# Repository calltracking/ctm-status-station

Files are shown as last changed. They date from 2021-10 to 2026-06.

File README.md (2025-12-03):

# CTM Status Station

Small ESP32 light bar that shows agent call status from CallTrackingMetrics.

## What it does
- Broadcasts its own setup AP on first boot so you can enter Wi‑Fi.
- Lets you link the device to a CTM account via the built-in web UI.
- Listens for ringing/active calls over WebSocket and updates LEDs.

## Hardware
- Tested on TinyPICO / ESP32-S3 dev kits with NeoPixel strip (8 LEDs by default).
- One button: BOOT/RESET. On TinyPICO it hard-resets the board; use the web “Factory Reset” instead.

## Quick start (first-time setup)
1) Power the device. It starts a hotspot:
   - ssid: `ctmlight`
   - pass: `ctmstatus`
2) Connect to the hotspot. A captive portal should pop up; if it doesn’t, open `http://192.168.4.1/` manually.
3) Enter your Wi‑Fi SSID and password. The device reboots and joins your network (LEDs blink green once connected).
4) Find its LAN IP (router/DHCP list or `http://ctmlight.local` if mDNS works) and open `http://<device-ip>/`.
5) Click **Connect Device** to start linking. You’ll get a code and a link to `https://app.calltrackingmetrics.com/accesscode`.
6) Approve the device in CTM. The page polls automatically; once linked the device reboots and starts listening.

## Relinking / factory reset
- From the UI: click **Factory Reset** (on the main page or `/link_setup`) to clear Wi‑Fi and CTM link, then the device reboots back to the `ctmlight` AP.
- If you’re still linked and you reopen `/link`, it will tell you the device is already linked and offer **Unlink Device**.

## Build & flash
Prereqs: PlatformIO (`pio`), Python, USB cable.

Common targets (default `make` builds/uploads TinyPICO):
```
make                         # TinyPICO: build, upload, then serial monitor
pio run -e tinypico          # build only TinyPICO
pio run -e s3wroom_1         # build only ESP32-S3 devkit
make wroom_s3                # ESP32-S3: build + upload
pio device monitor -b 115200 # serial monitor (921600 for s3wroom_1)
make clean                   # cleanup
```

## Development / tunnels
When `CTM_PRODUCTION` is undefined (staging/tunnel), provide hosts and client id:
```
CTM_SOC_HOST=<ngrok>.ngrok.io \
CTM_API_HOST=<ngrok>.ngrok.io \
CTM_APP_HOST=<ngrok>.ngrok.io \
CTM_CLIENTID=<client_id> \
make tinypico
```
Get a client id from https://app.calltrackingmetrics.com/oauth_apps/.

## Ethernet (experimental)
ESP32 Ethernet needs different PEM handling. Use the helper from OPEnSLab-OSU/SSLClient to generate BearSSL certs:
```
python3 pycert_bearssl.py download app.calltrackingmetrics.com --output include/certs.h
```

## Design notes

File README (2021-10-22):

= CTM Status Station

The goal this project is to make it easy to have light in a room that helps people in the area know when someone is on a phone call.

We'll subscribe to incoming phone calls and active call events and change the light color to make this obvious

= Setup

Before the device is configured it will expose an access point: 
  ssid: ctmlight
  pass: ctmstatus

After connecting navigate browser to

http://192.168.4.1/

From the web interface configure your networks ssid and password

Once the device joins your network it'll blink green

You'll have to find the device now on your network

http://your-device-ip/

From here you can click connect and you'll be taken to a page on https://app.calltrackingmetrics give access to the device and you should 
next be presented with some options to choose a specific team or your whole account.

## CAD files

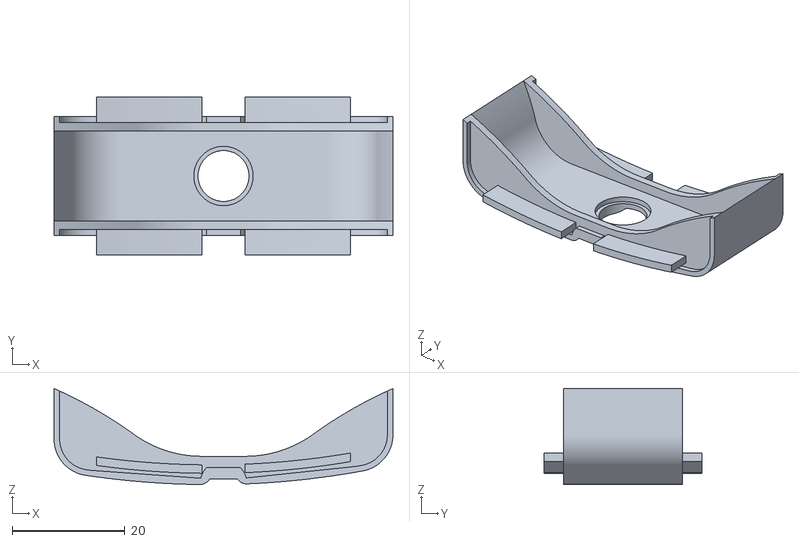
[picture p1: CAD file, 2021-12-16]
case/v2-a.stl
60.0 x 28.0 x 17.0

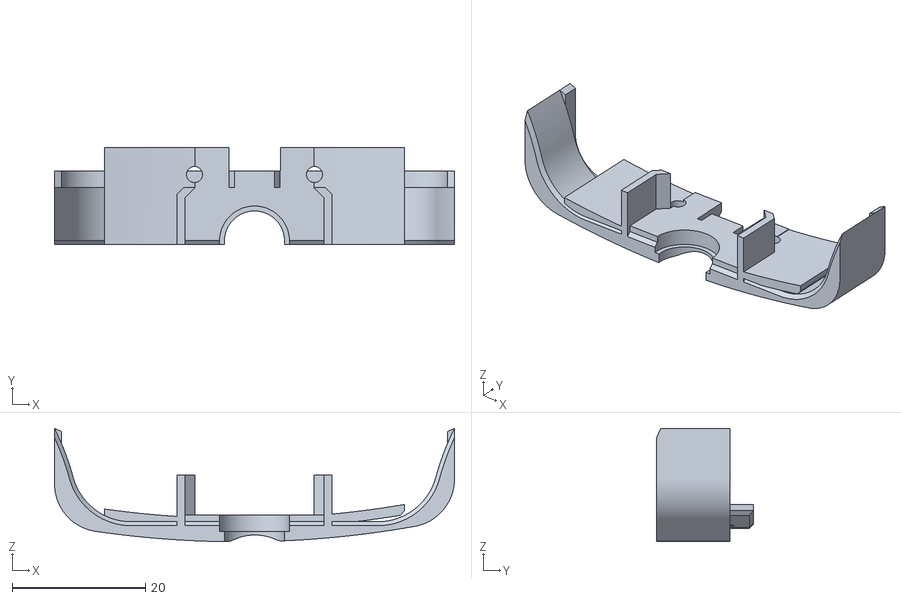
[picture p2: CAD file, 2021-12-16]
case/left.stl
60.0 x 14.5 x 17.0

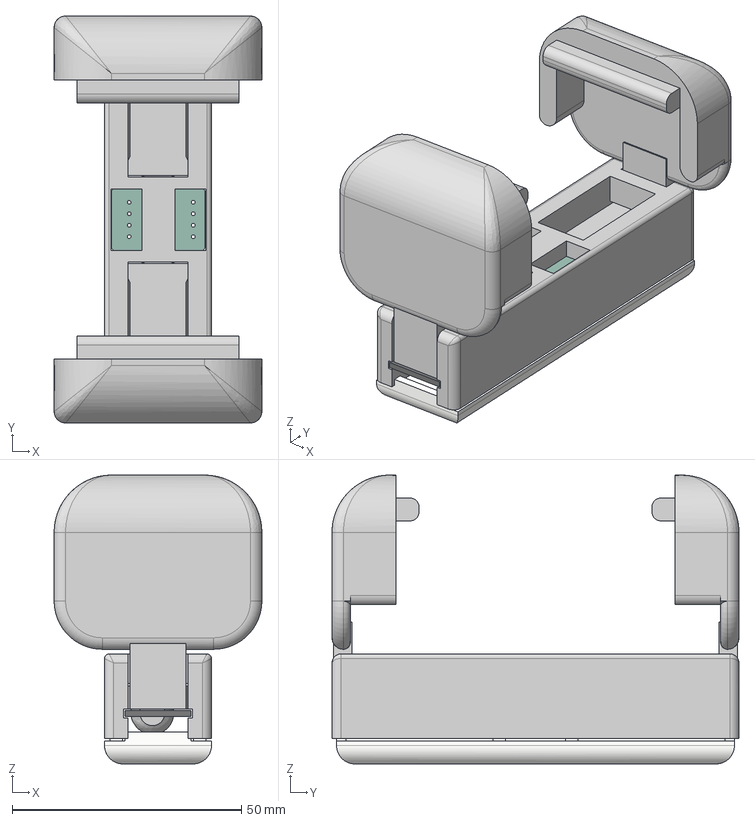
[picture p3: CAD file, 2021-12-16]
case/Case v19.step
45.3 x 88.8 x 63.0 mm

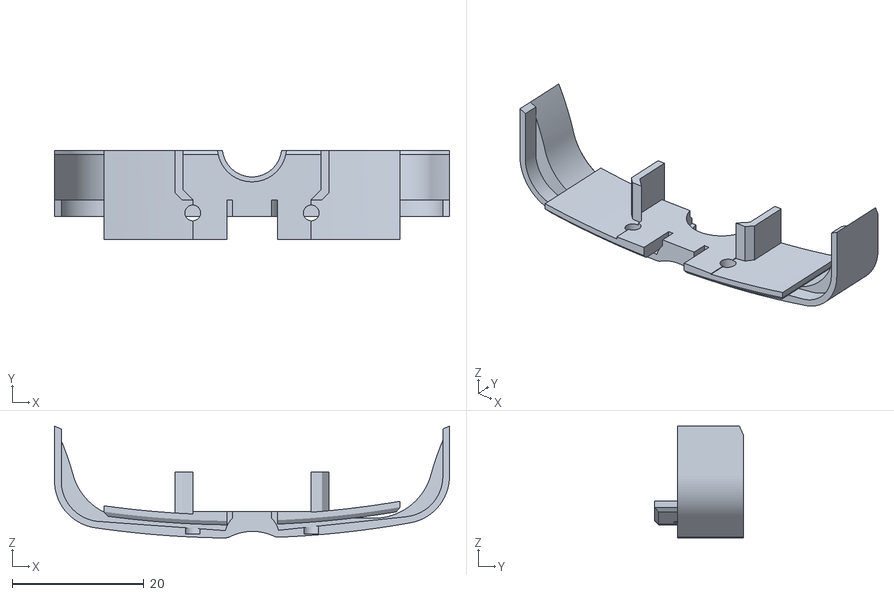
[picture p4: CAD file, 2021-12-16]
case/right.stl
60.0 x 13.5 x 17.0

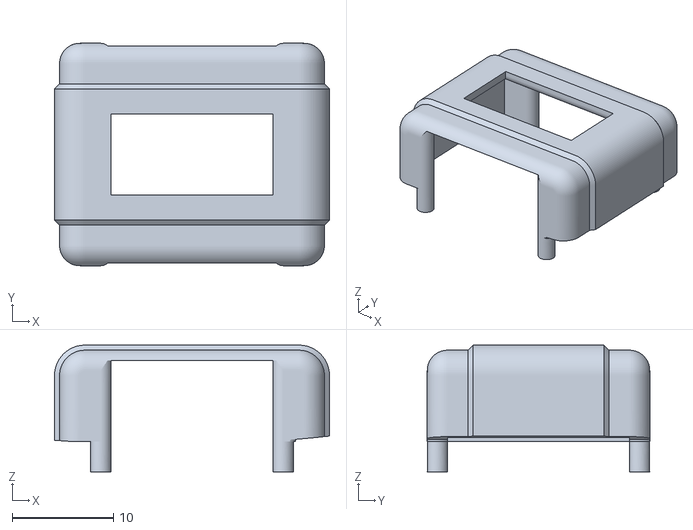
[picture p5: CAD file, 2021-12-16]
case/holder.stl
27.1 x 21.9 x 12.5

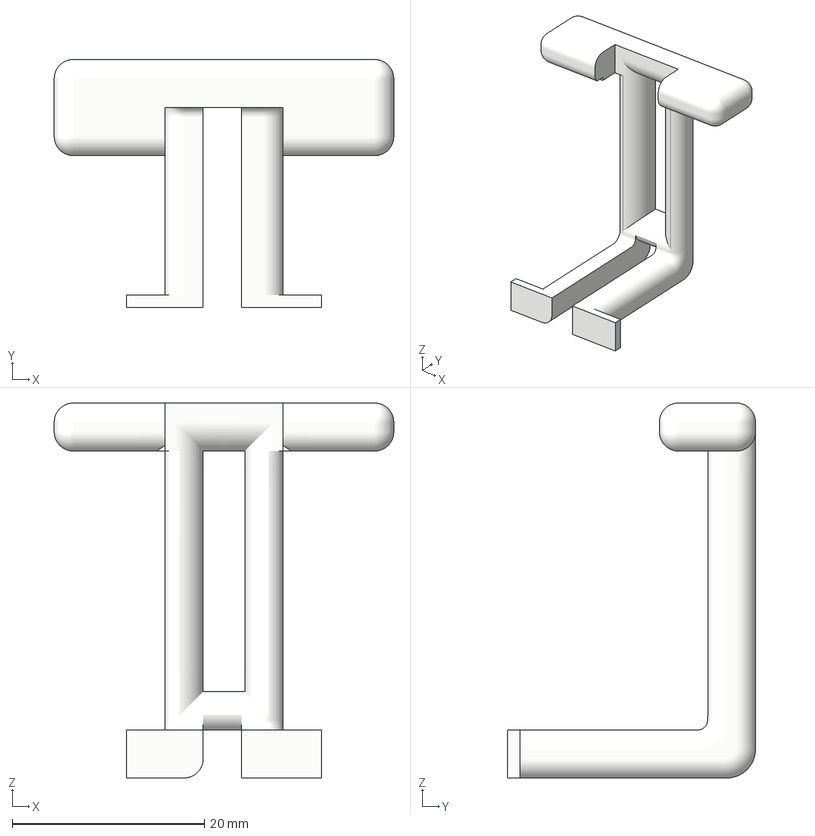
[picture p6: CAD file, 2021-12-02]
case/leg1.3mf
35.3 x 25.8 x 39.0 mm

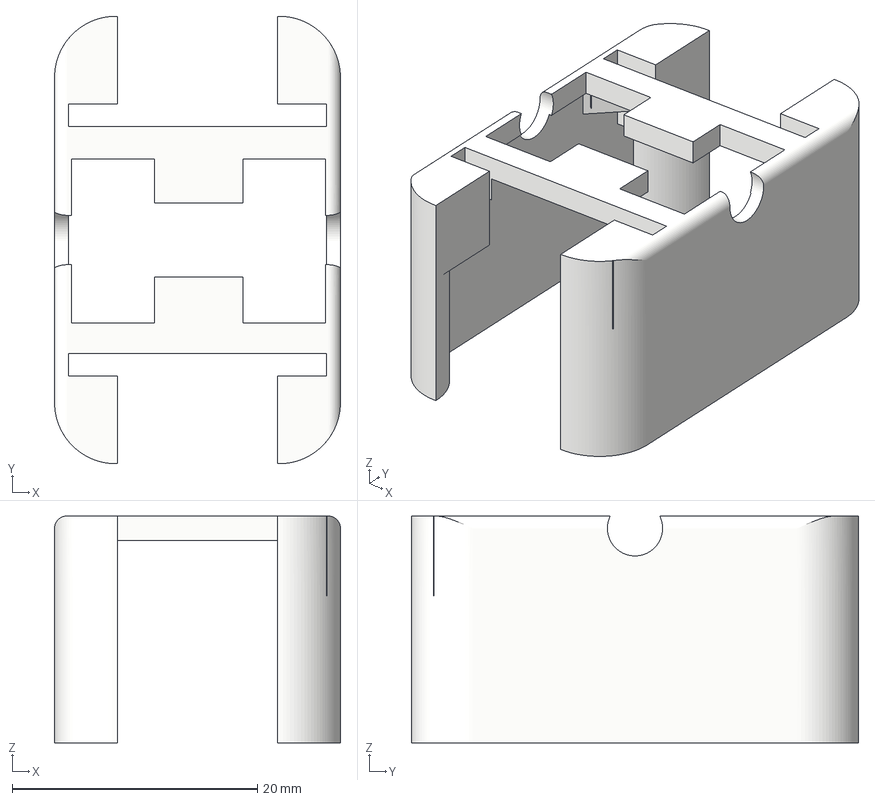
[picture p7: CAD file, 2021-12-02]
case/led-frame.3mf
23.3 x 36.5 x 18.5 mm

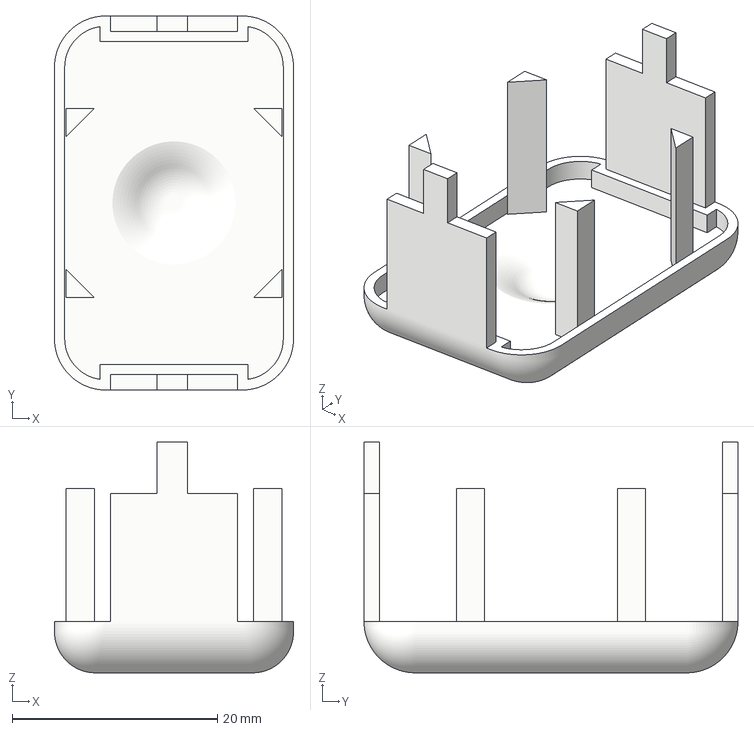
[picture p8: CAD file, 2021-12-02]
case/led-top.3mf
23.3 x 36.5 x 22.5 mm

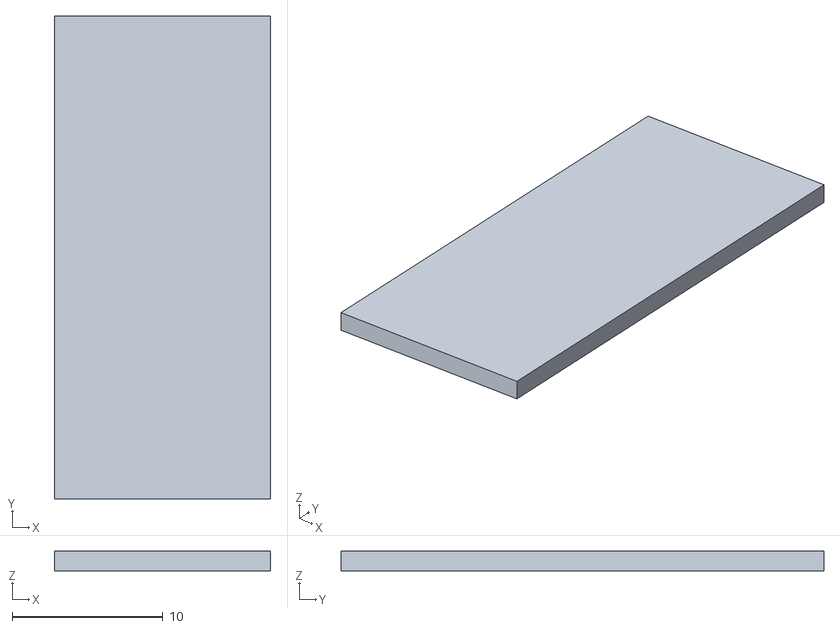
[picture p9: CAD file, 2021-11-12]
case/frame-lock2.stl
14.3 x 32.0 x 1.30

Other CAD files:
case/leg2.3mf
case/frame-lock1.stl
case/led-frame.stl
case/led-top.stl
case/leg1.stl
case/leg2.stl

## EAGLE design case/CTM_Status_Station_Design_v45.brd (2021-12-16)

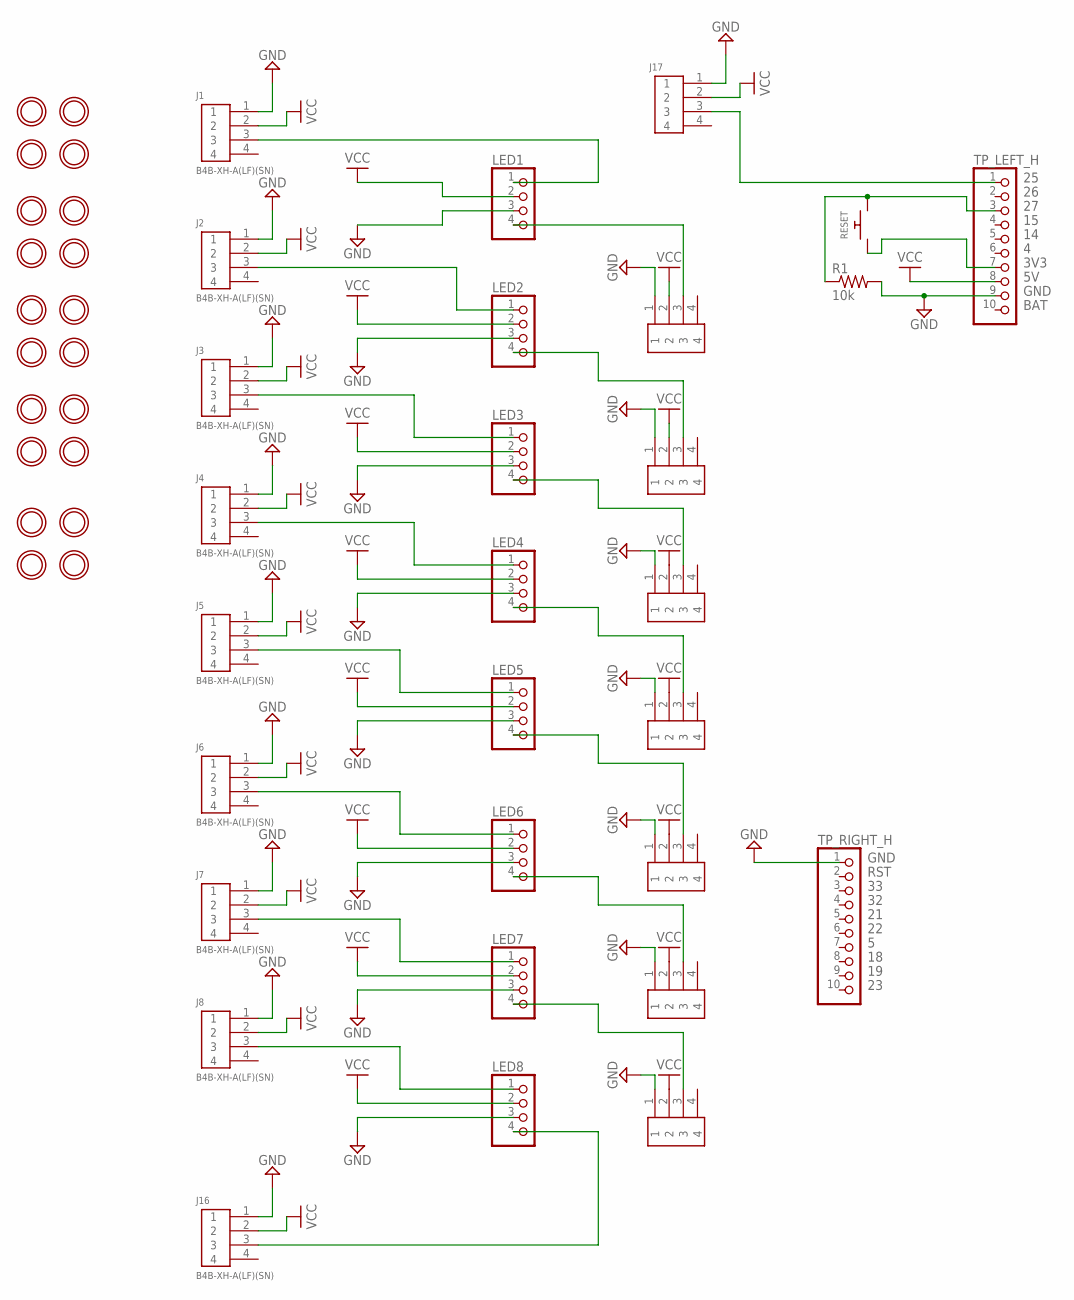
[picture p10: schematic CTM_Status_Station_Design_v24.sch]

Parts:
J1, J2, J3, J4, J5, J6, J7, J8, J9, J10, J11, J12, J13, J14, J15, J16, J17: B4B-XH-A(LF)(SN)
LED1, LED2, LED3, LED4, LED5, LED6, LED7, LED8: PINHD-1X4; 1X04
R1: 10k; 0207/7
RESET: SWITCH_PUSHBUTTONEVQ-PE; TACT_PANA-EVQ
TP_LEFT_H: PINHD-1X10; 1X10
TP_RIGHT_H: PINHD-1X10; 1X10
U$1, U$2, U$3, U$4, U$5, U$6, U$7, U$8, U$9, U$10, U$11, U$12, U$13, U$14, U$15, U$16, U$17, U$18, U$19, U$28: MOUNTINGHOLE2.5; MOUNTINGHOLE_2.5_PLATED

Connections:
3V3: RESET.P$1, TP_LEFT_H.7
DIN1: J1.3, LED1.1
DIN2: J2.3, LED2.1
DIN3: J3.3, LED3.1
DIN4: J4.3, LED4.1
DIN5: J5.3, LED5.1
DIN6: J6.3, LED6.1
DIN7: J7.3, LED7.1
DIN8: J8.3, LED8.1
DOUT: J17.3, TP_LEFT_H.1
DOUT1: J10.3, LED1.4
DOUT2: J9.3, LED2.4
DOUT3: J11.3, LED3.4
DOUT4: J12.3, LED4.4
DOUT5: J13.3, LED5.4
DOUT6: J14.3, LED6.4
DOUT7: J15.3, LED7.4
DOUT8: J16.3, LED8.4
GND: J1.1, J2.1, J3.1, J4.1, J5.1, J6.1, J7.1, J8.1, J9.1, J10.1, J11.1, J12.1, J13.1, J14.1, J15.1, J16.1, J17.1, LED1.3, LED2.3, LED3.3, LED4.3, LED5.3, LED6.3, LED7.3, LED8.3, R1.2, TP_LEFT_H.9, TP_RIGHT_H.1
RESET: R1.1, RESET.P$2, TP_LEFT_H.3
VCC: J1.2, J2.2, J3.2, J4.2, J5.2, J6.2, J7.2, J8.2, J9.2, J10.2, J11.2, J12.2, J13.2, J14.2, J15.2, J16.2, J17.2, LED1.2, LED2.2, LED3.2, LED4.2, LED5.2, LED6.2, LED7.2, LED8.2, TP_LEFT_H.8

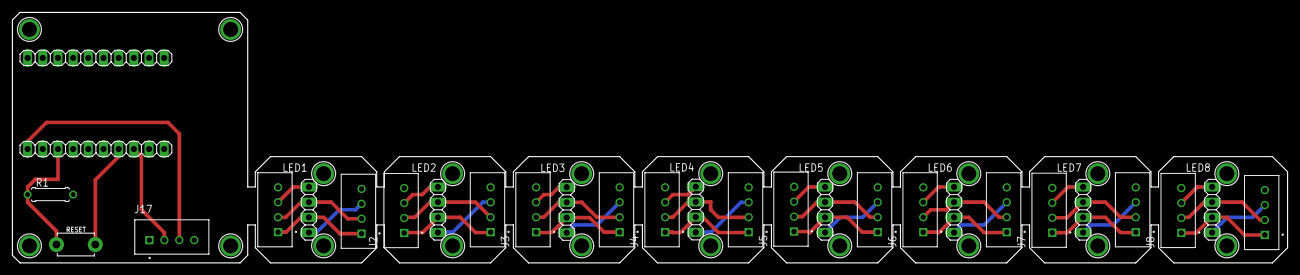
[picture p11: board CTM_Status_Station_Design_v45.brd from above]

Board: 2 copper layers, 213.4 x 41.9 mm, 49 parts (0 on the bottom side), 21 nets.

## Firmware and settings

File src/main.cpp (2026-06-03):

// Copyright (c) 2011-2025 CallTrackingMetrics
// SPDX-License-Identifier: ISC

/**
 * configure and listen for account or team events
 */
#define CTM_PRODUCTION

//#define LIGHT_TEST
#ifndef HAS_DISPLAY
#ifndef WROOM_PINS
#include <TinyPICO.h>
#endif
#endif

#include <SPI.h>
#include <WiFi.h>
#include <WebServer.h>
#include <WiFiClientSecure.h>
#include <HTTPClient.h>
#include <Wire.h>
#include <DNSServer.h>
#include <cstring>
#include <esp_system.h>
#include <esp_timer.h>
#include <ArduinoJson.h> // see: https://arduinojson.org/v6/api/jsonobject/containskey/
#include <ArduinoWebsockets.h>
#include <Adafruit_NeoPixel.h>

#include <WiFiClientSecure.h>

#ifdef HAS_DISPLAY
  #include <Adafruit_GFX.h>
  #include <Adafruit_ThinkInk.h>

  #ifdef ESP32
    #define SRAM_CS     32
    #define EPD_CS      15
    #define EPD_DC      33  
  #endif
#endif

#ifdef __AVR__
 #include <avr/power.h> // Required for 16 MHz Adafruit Trinket
#endif

#include "settings.h"
#include "url_utils.h"
#include "light_logic.h"

#ifdef HAS_DISPLAY

#define EPD_RESET   -1 // can set to -1 and share with microcontroller Reset!
#define EPD_BUSY    -1 // can set to -1 to not use a pin (will wait a fixed delay)

// Uncomment the following line if you are using 2.13" Monochrome EPD with SSD1680
//ThinkInk_213_Mono_BN display(EPD_DC, EPD_RESET, EPD_CS, SRAM_CS, EPD_BUSY);
ThinkInk_213_Mono_B72 display(EPD_DC, EPD_RESET, EPD_CS, SRAM_CS, EPD_BUSY);
//ThinkInk_213_Mono_B73 display(EPD_DC, EPD_RESET, EPD_CS, SRAM_CS, EPD_BUSY);
#define COLOR1 EPD_BLACK
#define COLOR2 EPD_RED

#endif

#ifdef TINYPICO_PINS
#define RESET_BUTTON 0           // TinyPICO BOOT button
#define RESET_BUTTON_ACTIVE LOW  // active-low (pulled up)
#else
#define RESET_BUTTON 27
#define RESET_BUTTON_ACTIVE HIGH
#endif
#define STATUS_LIGHT_OUT 25
#define DO_EXPAND(VAL)  VAL ## 1
#define EXPAND(VAL)     DO_EXPAND(VAL)

#ifdef CTM_PRODUCTION
#if !defined(APP_HOST) || (EXPAND(APP_HOST) == 1)
#undef APP_HOST
#define APP_HOST "app.calltrackingmetrics.com"
#endif
#if !defined(API_HOST) || (EXPAND(API_HOST) == 1)
#undef API_HOST
#define API_HOST "api.calltrackingmetrics.com"
#endif
#if !defined(SOC_HOST) || (EXPAND(SOC_HOST) == 1)
#undef SOC_HOST
#define SOC_HOST "app.calltrackingmetrics.com"
#endif
#if !defined(CLIENTID) || (EXPAND(CLIENTID) == 1)
#undef CLIENTID
#define CLIENTID "udaRmKY2W_85tFPM6f92R9aG8i-VwPjfQT1Q8RI8qIg"
#endif

// amazon root ca for api.calltrackingmetrics.com secure connections
const char *root_ca="-----BEGIN CERTIFICATE-----\n"
"MIIDQTCCAimgAwIBAgITBmyfz5m/jAo54vB4ikPmljZbyjANBgkqhkiG9w0BAQsF\n"
"ADA5MQswCQYDVQQGEwJVUzEPMA0GA1UEChMGQW1hem9uMRkwFwYDVQQDExBBbWF6\n"
"b24gUm9vdCBDQSAxMB4XDTE1MDUyNjAwMDAwMFoXDTM4MDExNzAwMDAwMFowOTEL\n"
"MAkGA1UEBhMCVVMxDzANBgNVBAoTBkFtYXpvbjEZMBcGA1UEAxMQQW1hem9uIFJv\n"
"b3QgQ0EgMTCCASIwDQYJKoZIhvcNAQEBBQADggEPADCCAQoCggEBALJ4gHHKeNXj\n"
"ca9HgFB0fW7Y14h29Jlo91ghYPl0hAEvrAIthtOgQ3pOsqTQNroBvo3bSMgHFzZM\n"
"9O6II8c+6zf1tRn4SWiw3te5djgdYZ6k/oI2peVKVuRF4fn9tBb6dNqcmzU5L/qw\n"
"IFAGbHrQgLKm+a/sRxmPUDgH3KKHOVj4utWp+UhnMJbulHheb4mjUcAwhmahRWa6\n"
"VOujw5H5SNz/0egwLX0tdHA114gk957EWW67c4cX8jJGKLhD+rcdqsq08p8kDi1L\n"
"93FcXmn/6pUCyziKrlA4b9v7LWIbxcceVOF34GfID5yHI9Y/QCB/IIDEgEw+OyQm\n"
"jgSubJrIqg0CAwEAAaNCMEAwDwYDVR0TAQH/BAUwAwEB/zAOBgNVHQ8BAf8EBAMC\n"
"AYYwHQYDVR0OBBYEFIQYzIU07LwMlJQuCFmcx7IQTgoIMA0GCSqGSIb3DQEBCwUA\n"
"A4IBAQCY8jdaQZChGsV2USggNiMOruYou6r4lK5IpDB/G/wkjUu0yKGX9rbxenDI\n"
"U5PMCCjjmCXPI6T53iHTfIUJrU6adTrCC2qJeHZERxhlbI1Bjjt/msv0tadQ1wUs\n"
"N+gDS63pYaACbvXy8MWy7Vu33PqUXHeeE6V/Uq2V8viTO96LXFvKWlJbYK8U90vv\n"
"o/ufQJVtMVT8QtPHRh8jrdkPSHCa2XV4cdFyQzR1bldZwgJcJmApzyMZFo6IQ6XU\n"
"5MsI+yMRQ+hDKXJioaldXgjUkK642M4UwtBV8ob2xJNDd2ZhwLnoQdeXeGADbkpy\n"
"rqXRfboQnoZsG4q5WTP468SQvvG5\n"
"-----END CERTIFICATE-----";
//#endif

#else
/* *.ngrok.io root cert */
const char *root_ca="-----BEGIN CERTIFICATE-----\n"
"MIIFazCCA1OgAwIBAgIRAIIQz7DSQONZRGPgu2OCiwAwDQYJKoZIhvcNAQELBQAw\n"
"TzELMAkGA1UEBhMCVVMxKTAnBgNVBAoTIEludGVybmV0IFNlY3VyaXR5IFJlc2Vh\n"
"cmNoIEdyb3VwMRUwEwYDVQQDEwxJU1JHIFJvb3QgWDEwHhcNMTUwNjA0MTEwNDM4\n"
"WhcNMzUwNjA0MTEwNDM4WjBPMQswCQYDVQQGEwJVUzEpMCcGA1UEChMgSW50ZXJu\n"
"ZXQgU2VjdXJpdHkgUmVzZWFyY2ggR3JvdXAxFTATBgNVBAMTDElTUkcgUm9vdCBY\n"
"MTCCAiIwDQYJKoZIhvcNAQEBBQADggIPADCCAgoCggIBAK3oJHP0FDfzm54rVygc\n"
"h77ct984kIxuPOZXoHj3dcKi/vVqbvYATyjb3miGbESTtrFj/RQSa78f0uoxmyF+\n"
"0TM8ukj13Xnfs7j/EvEhmkvBioZxaUpmZmyPfjxwv60pIgbz5MDmgK7iS4+3mX6U\n"
"A5/TR5d8mUgjU+g4rk8Kb4Mu0UlXjIB0ttov0DiNewNwIRt18jA8+o+u3dpjq+sW\n"
"T8KOEUt+zwvo/7V3LvSye0rgTBIlDHCNAymg4VMk7BPZ7hm/ELNKjD+Jo2FR3qyH\n"
"B5T0Y3HsLuJvW5iB4YlcNHlsdu87kGJ55tukmi8mxdAQ4Q7e2RCOFvu396j3x+UC\n"
"B5iPNgiV5+I3lg02dZ77DnKxHZu8A/lJBdiB3QW0KtZB6awBdpUKD9jf1b0SHzUv\n"
"KBds0pjBqAlkd25HN7rOrFleaJ1/ctaJxQZBKT5ZPt0m9STJEadao0xAH0ahmbWn\n"
"OlFuhjuefXKnEgV4We0+UXgVCwOPjdAvBbI+e0ocS3MFEvzG6uBQE3xDk3SzynTn\n"
"jh8BCNAw1FtxNrQHusEwMFxIt4I7mKZ9YIqioymCzLq9gwQbooMDQaHWBfEbwrbw\n"
"qHyGO0aoSCqI3Haadr8faqU9GY/rOPNk3sgrDQoo//fb4hVC1CLQJ13hef4Y53CI\n"
"rU7m2Ys6xt0nUW7/vGT1M0NPAgMBAAGjQjBAMA4GA1UdDwEB/wQEAwIBBjAPBgNV\n"
"HRMBAf8EBTADAQH/MB0GA1UdDgQWBBR5tFnme7bl5AFzgAiIyBpY9umbbjANBgkq\n"
"hkiG9w0BAQsFAAOCAgEAVR9YqbyyqFDQDLHYGmkgJykIrGF1XIpu+ILlaS/V9lZL\n"
"ubhzEFnTIZd+50xx+7LSYK05qAvqFyFWhfFQDlnrzuBZ6brJFe+GnY+EgPbk6ZGQ\n"
"3BebYhtF8GaV0nxvwuo77x/Py9auJ/GpsMiu/X1+mvoiBOv/2X/qkSsisRcOj/KK\n"
"NFtY2PwByVS5uCbMiogziUwthDyC3+6WVwW6LLv3xLfHTjuCvjHIInNzktHCgKQ5\n"
"ORAzI4JMPJ+GslWYHb4phowim57iaztXOoJwTdwJx4nLCgdNbOhdjsnvzqvHu7Ur\n"
"TkXWStAmzOVyyghqpZXjFaH3pO3JLF+l+/+sKAIuvtd7u+Nxe5AW0wdeRlN8NwdC\n"
"jNPElpzVmbUq4JUagEiuTDkHzsxHpFKVK7q4+63SM1N95R1NbdWhscdCb+ZAJzVc\n"
"oyi3B43njTOQ5yOf+1CceWxG1bQVs5ZufpsMljq4Ui0/1lvh+wjChP4kqKOJ2qxq\n"
"4RgqsahDYVvTH9w7jXbyLeiNdd8XM2w9U/t7y0Ff/9yi0GE44Za4rF2LN9d11TPA\n"
"mRGunUHBcnWEvgJBQl9nJEiU0Zsnvgc/ubhPgXRR4Xq37Z0j4r7g1SgEEzwxA57d\n"
"emyPxgcYxn/eR44/KJ4EBs+lVDR3veyJm+kXQ99b21/+jh5Xos1AnX5iItreGCc=\n"
"-----END CERTIFICATE-----";
//#endif

#define STRINGIZE(x) #x
#define STRINGIZE_VALUE_OF(x) STRINGIZE(x)
#define API_HOST STRINGIZE_VALUE_OF(CTM_API_HOST)
#define APP_HOST STRINGIZE_VALUE_OF(CTM_APP_HOST)
#define SOC_HOST STRINGIZE_VALUE_OF(CTM_SOC_HOST)
#define CLIENTID STRINGIZE_VALUE_OF(CTM_CLIENTID)


#endif



const char *default_ssid = "ctmlight";
const char *default_pass = "ctmstatus";
static char html_buffer[9892]; // we use about 5486 without custom statues
static char html_error[64];
bool socketClosed = false;
bool linkPending = false;
bool linkError = false;
bool linkTimerPending = false; // waiting for token device code
uint64_t resetPressStart = 0;
bool resetWasPressed = false;
const uint64_t RESET_HOLD_MS = 5000; // hold BOOT for 5s to factory reset
// allow multi-reset fallback (works even if BOOT button wiring resets the board)
RTC_DATA_ATTR uint64_t lastBootUs;      // retained across resets if RTC power stays up
RTC_DATA_ATTR uint8_t resetCycleCount;
RTC_DATA_ATTR uint32_t resetMagic;
uint32_t lastLinkTimerCheck = 0;
uint32_t lastPing = 0;
uint32_t lastStatusCheck = 0;
#ifdef CTM_UNIT_TEST
bool refresh_called_flag = false;
#endif
int LocateLED = -1;
int locateCycles = 0;
String captoken;
bool hasAuthGranted = false;
Ringer ringers[RINGERS+1]; // set of led's to blink for ringing

Settings conf;
websockets::WebsocketsClient socket;
IPAddress DeviceIP;
unsigned long WIFIReConnectInteval = 30000;
unsigned long previousWifiMillis = 0;
WebServer server(80);
DNSServer dnsServer;
const byte DNS_PORT = 53;


bool IsLocalAP = true;
bool apActive = false; // true while softAP is running
bool staConnectInProgress = false;
bool staConnectFailed = false;
uint64_t staConnectStart = 0;
uint64_t apGraceStart = 0;
uint64_t AP_GRACE_MS = 12000; // keep AP alive after STA connect so UI can redirect
Adafruit_NeoPixel *pixels;
bool hasSocketConnected = false;
#ifdef CTM_UNIT_TEST
bool debug_socket_message_entered = false;
bool debug_socket_message_has_fields = false;
bool debug_socket_message_status_branch = false;
bool debug_socket_message_has_id = false;
int  debug_socket_agent_id = -1;
int  debug_socket_led_index = -1;
int  debug_socket_data_id = -1;
String debug_socket_payload_str;
String debug_socket_status_value;
bool debug_socket_has_status = false;
String debug_socket_data_keys;
#endif

void setup_https(WiFiClientSecure *client, HTTPClient *http, const String &host, const String &path) {
  client->setCACert(root_ca);
  Serial.println("setup secure wifi client");
  http->setConnectTimeout(10000);// timeout in ms
  http->setTimeout(10000); // 10 seconds
  Serial.println("timers set");
  String url = String("https://") + host + path;
  Serial.println("begin client");
  http->begin(*client, url);
  Serial.println("https client ready");
}

void handle_Style();
void handle_Script();
void handle_Main();
void handle_Conf();
void handle_LinkSetup();
void handle_LinkStatus();
void handle_Link();
void handle_Unlink();
void handle_Linked();
void handle_FactoryReset();
void handle_AgentLookup();
void handle_CaptivePortal();
void handle_IpStatus();
void handle_SaveAgents();
void handle_SaveColors();
void handle_LocateLED();
void handle_FlipRedGreen();
void handleNotFound();
void checkTokenStatus();
void socketEvent(websockets::WebsocketsEvent event, String data);
void socketMessage(websockets::WebsocketsMessage message);
void updateAgentStatusLed(int index, const String status);
void refreshAccessToken();
bool refreshCapToken(int attempts=0);
void startWebsocket();
void dnsPreload(const char *name);

char from_hex(char ch);
char to_hex(char code);
String url_encode(String str);
bool red_green_flipped = false;

void blinkGreen();
void blinkOrange();
void blinkBlue();

void lightTestCycle();
void tickLoopOnce(uint32_t now);

void refreshAllAgentStatus();
void fetchCustomStatus(); 

#ifndef CTM_UNIT_TEST
// fetch current status information for the given agent for the led at index
void fetchLedAgentStatus(int index) {
  if (!conf.leds[index]) { return; }
  int agentId = conf.leds[index];
  Serial.printf("fetching status for agent: %d\n", agentId);

  WiFiClientSecure client;
  HTTPClient http;
  String path = String("/api/v1/accounts/") + conf.account_id + "/agents/" + agentId;
  setup_https(&client, &http, API_HOST, path);

  http.addHeader("Authorization", String("Bearer ") + conf.access_token);
  int r = http.GET();
  String body = http.getString();
  http.end();
  Serial.println(body);
  if (r < 0) {
    Serial.println("error issuing device request");
    return;
  }
  JsonDocument doc;
  DeserializationError error = deserializeJson(doc, body);
  if (error) {
    Serial.print(F("deserializeJson() failed: "));
    Serial.println(path);
    return;
  }
  JsonObject obj = doc.as<JsonObject>();
  if (obj.containsKey("name")) {
    Serial.printf("update name for agent: %s\n", (const char*)obj["name"]);
    snprintf(conf.agentNames[index], 32, "%s", (const char*)obj["name"]);
    conf.save();
  }

  if (obj.containsKey("access") && obj["access"] == "denied") { // {"access":"denied"}
    Serial.printf("access denied\n");
    //updateAgentStatusLed(index, "offline");
    setError(index);
    pixels->show();
  } else if (obj.containsKey("status") && obj["status"]) {
    Serial.printf("got status: %s for led %d\n", (const char*)obj["status"], index);
    updateAgentStatusLed(index, obj["status"]);
  } else {
    Serial.printf("no status mark offline\n");
    updateAgentStatusLed(index, "offline");
  }
}
#else
void fetchLedAgentStatus(int) {}
#endif

void testdrawtext(const char *text, uint16_t color, int line=0) {
#ifdef HAS_DISPLAY
  display.setCursor(20, (line+1)*20);
  display.setTextColor(color);
  display.setTextWrap(true);
  display.print(text);
#endif
}
#ifdef HAS_DISPLAY
#else
#endif

#ifndef CTM_UNIT_TEST
// GCOVR_EXCL_START
void setup() {
  Serial.begin(115200);

  delay(1000);
#ifdef HAS_DISPLAY
  display.begin();
  display.clearBuffer();
  testdrawtext("CallTrackingMetrics... Loading", COLOR1, 1);
  display.display();
#endif

  conf.begin();
  // keep UI/link status in sync across reboots while waiting for user auth
  linkPending = conf.ctm_user_pending;
  // wifi setup required
  if (conf.ssid && conf.pass && strnlen(conf.ssid, 32) > 0) {
    if (strnlen(conf.ssid, 33) == 33) {
      Serial.printf("ssid and pass not configured or eeprom is corrupted and must be reset\n");
      conf.reset();
      conf.save();
    } else {
      Serial.printf("ssid: %s, pass: %s\n", conf.ssid, conf.pass);
    }
  }
#ifdef HAS_BUTTON
  // TinyPICO BOOT button is active-low; use pull-up. Dev kits keep existing wiring.
#ifdef TINYPICO_PINS
  pinMode(RESET_BUTTON, INPUT_PULLUP);
#else
  pinMode(RESET_BUTTON, INPUT);
#endif
  Serial.println("button setup");
#endif

#ifdef HAS_BUTTON
  // allow factory reset if BOOT/RESET button is held during power-up
  if (digitalRead(RESET_BUTTON) == RESET_BUTTON_ACTIVE) {
    Serial.println("BOOT held on startup -> clearing WiFi/CTM settings");
    setRedAll();
    conf.reset();
    conf.save();
    delay(500);
    ESP.restart();
  }

  // fallback: triple quick reset within 8 seconds to clear settings (works even if BOOT triggers a reset)
  uint64_t nowUs = esp_timer_get_time();
  if (resetMagic != 0xCAFEBABE) {
    resetMagic = 0xCAFEBABE;
    resetCycleCount = 0;
    lastBootUs = 0;
  }
  Serial.printf("Reset reason: %d\n", esp_reset_reason());
  Serial.printf("RTC resetCycleCount=%u lastBootUs=%llu now=%llu\n", resetCycleCount, (unsigned long long)lastBootUs, (unsigned long long)nowUs);
  if (lastBootUs == 0 || (nowUs - lastBootUs) > 8000000ULL) { // >8s since last boot
    resetCycleCount = 1;
  } else {
    resetCycleCount++;
  }
  lastBootUs = nowUs;
  if (resetCycleCount >= 3) {
    Serial.println("Triple reset detected -> clearing WiFi/CTM settings");
    setRedAll();
    conf.reset();
    conf.save();
    delay(300);
    ESP.restart();
  }
#endif

  pixels = new Adafruit_NeoPixel(LED_COUNT, STATUS_LIGHT_OUT, NEO_GRB + NEO_KHZ800);
  pixels->begin(); // INITIALIZE NeoPixel strip object (REQUIRED)
  setBlueAll();
  for (int i = 0; i < RINGERS; ++i) {
    ringers[i].on = false;
    ringers[i].high = false;
    ringers[i].lastRing = 0;
  }
#ifdef LIGHT_TEST
  delay(1000);
  return;
#endif

  if (conf.good() && conf.wifi_configured && strlen(conf.ssid) > 0) {
    bool wifiConnected = false;
    for (int attempt = 1; attempt <= 2; ++attempt) {
      Serial.printf("Connecting to network (attempt %d)...\n", attempt);
      WiFi.begin(conf.ssid, conf.pass);
      if (WiFi.waitForConnectResult() == WL_CONNECTED) {
        wifiConnected = true;
        setGreenAll();
        break;
      }
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
void loop() {
  tickLoopOnce(millis());
}
void handle_Unlink() {
  conf.ctm_configured = false;
  conf.ctm_user_pending = false;
  conf.expires_in = 0;
  conf.account_id = 0;
  conf.team_id = 0;
  linkPending = false;
  linkError = false;

  memset(conf.device_code, 0, sizeof(conf.device_code));
  memset(conf.access_token, 0, sizeof(conf.access_token));
  memset(conf.refresh_token, 0, sizeof(conf.refresh_token));
  
  conf.save();
  server.sendHeader("Location","/");
  server.send(303);
}

void handle_FactoryReset() {
  Serial.println("factory reset requested via UI");
  setRedAll();
  conf.reset();
  conf.save();
  WiFi.disconnect(true);
  snprintf(html_buffer, sizeof(html_buffer),
    "<html><head><meta name='viewport' content='width=device-width, initial-scale=1'><title>Resetting</title></head>"
    "<body style='font-family:Helvetica;text-align:center'>"
    "<h2>Resetting...</h2><p>Clearing WiFi and CTM link, rebooting to setup AP.</p>"
    "</body></html>");
  server.send(200, "text/html", html_buffer);
  delay(500);
  ESP.restart();
}

void handle_Linked() {
  snprintf(html_buffer, 4096, "<html>"
    "<head><meta name=\"viewport\" content=\"width=device-width, initial-scale=1\">"
    "<link rel=\"icon\" href=\"data:,\">"
    "<style>html { font-family: Helvetica; display: inline-block; margin: 0px auto; text-align: center;}"
    ".button { background-color: #4CAF50; border: none; color: white; padding: 16px 40px;"
    "text-decoration: none; font-size: 30px; margin: 2px; cursor: pointer;}"
    ".button2 {background-color: #555555;}</style></head>"
    
    "<body><h1>Success</h1><p>Status light should be following your agents</p>"
    "</body>"
    "</html>");
  server.send(200, "text/html", html_buffer);
}

void handle_SaveColors() {
  // reset
  for (int i = 0; i < MAX_CUSTOM_STATUS; ++i) {
    String redKey = i + String("[red]");
    if (server.hasArg(redKey)) {
      conf.custom_status_color[i][0] = server.arg(redKey).toInt();
    } else {
      conf.custom_status_color[i][0] = 0;
    }

    String greenKey = i + String("[green]");
    if (server.hasArg(greenKey)) {
      conf.custom_status_color[i][1] = server.arg(greenKey).toInt();
    } else {
      conf.custom_status_color[i][1] = 0;
    }

    String blueKey = i + String("[blue]");
    if (server.hasArg(blueKey)) {
      conf.custom_status_color[i][2] = server.arg(blueKey).toInt();
    } else {
      conf.custom_status_color[i][2] = 0;
    }
  }
  conf.save();
  refreshAllAgentStatus();
  server.sendHeader("Location","/");
  server.send(303);
}

void handle_FlipRedGreen() {
  Serial.println("flip red green\n");
  if (red_green_flipped) {
    red_green_flipped = conf.red_green_flipped = false;
  } else {
    red_green_flipped = conf.red_green_flipped = true;
  }
  if (red_green_flipped) {
    Serial.println("now flipped: to true");
  } else {
    Serial.println("now flipped: to false");
  }
  conf.save();
  server.sendHeader("Location","/");
  server.send(303);
}

void handle_LocateLED() {
  LocateLED = server.arg("led").toInt() - 1;
  locateCycles = 0; 
  server.send(200, "application/json", "{}");
}

void handle_SaveAgents() {
  // erase name data we'll get it again while fetching status
  for (int i = 0; i < LED_COUNT; ++i) {
    memset(conf.agentNames[i], 0, 32);
  }
  for (int i = 0; i < LED_COUNT; ++i) {
    String ledkey = String("led") + i;
    conf.leds[i] = 0; // zero the led out
    if (server.hasArg(ledkey)) {
      conf.leds[i] = server.arg(ledkey).toInt();
    }
  }
  conf.save();
  refreshAllAgentStatus();
  server.sendHeader("Location","/");
  server.send(303);
}

#ifndef CTM_UNIT_TEST
void handle_AgentLookup() {
  String path = String("/api/v1/");
  if (server.hasArg("q")) {
    path += "lookup.json?descriptions=1&global=0&idstr=0&object_type=user&search=" + url_encode(server.arg("q"));
  } else if (server.hasArg("term")) {
    path += "lookupids.json?descriptions=1&global=0&idstr=0&object_type=user&ids[]=" + server.arg("term");
  } else {
    path += "lookup.json?descriptions=1&global=0&object_type=user&idstr=0";
  }
  Serial.printf("lookup: %s\n", path.c_str());
  WiFiClientSecure client;
  HTTPClient http;
  setup_https(&client, &http, API_HOST, path);

  http.addHeader("Authorization", String("Bearer ") + conf.access_token);

  int r = http.GET();
  String body = http.getString();
  http.end();

  if (r < 0) {
    Serial.println("error issuing device request");
  }
  JsonDocument doc;
  DeserializationError error = deserializeJson(doc, body);
  if (error) {
    Serial.print(F("deserializeJson() failed: "));
    Serial.println(path);
    return;
  }

  JsonObject obj = doc.as<JsonObject>();
  if (obj.containsKey("authentication")) {
    refreshAccessToken();
    server.send(403, "application/json", body);// "{ \"results\": [], \"pagination\": { \"more\": false } }"); // Send HTTP status 404 (Not Found) when there's no handler for the URI in the request
  } else {
    server.send(200, "application/json", body);// "{ \"results\": [], \"pagination\": { \"more\": false } }"); // Send HTTP status 404 (Not Found) when there's no handler for the URI in the request
  }
}
#else
void handle_AgentLookup() { server.send(200, "application/json", "{}"); }
#endif

// Send a redirect back to the local setup page for captive portal probes
void handle_CaptivePortal() {
  if (IsLocalAP && !conf.wifi_configured) {
    server.sendHeader("Location", String("http://") + DeviceIP.toString());
    server.send(302, "text/plain", "Redirecting to setup...");
    return;
  }
  server.send(204, "text/plain", "");
}

// Report current network state so the captive portal page can redirect to the STA IP
void handle_IpStatus() {
  IPAddress staIp = WiFi.localIP();
  IPAddress apIp = WiFi.softAPIP();
  bool connected = WiFi.status() == WL_CONNECTED && staIp != (uint32_t)0;
  snprintf(html_buffer, sizeof(html_buffer),
           "{\"connected\":%s,\"ip\":\"%s\",\"ap\":\"%s\",\"failed\":%s}",
           connected ? "true" : "false",
           staIp.toString().c_str(),
           apIp.toString().c_str(),
           staConnectFailed ? "true" : "false");
  server.send(200, "application/json", html_buffer);
}

void handleNotFound() {
  if (IsLocalAP && !conf.wifi_configured) {
    // force captive portal browsers back to root
    server.sendHeader("Location", String("http://") + DeviceIP.toString());
    server.send(302, "text/plain", "Redirecting to setup...");
    return;
  }
  server.send(404, "text/plain", "404: Not found"); // Send HTTP status 404 (Not Found) when there's no handler for the URI in the request
}
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

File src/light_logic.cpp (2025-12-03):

// Copyright (c) 2011-2025 CallTrackingMetrics
// SPDX-License-Identifier: ISC

#include "light_logic.h"

extern Adafruit_NeoPixel *pixels;
extern bool red_green_flipped;
extern Settings conf;
extern Ringer ringers[RINGERS + 1];
extern int LocateLED;
extern int locateCycles;
extern void refreshAllAgentStatus();

void setRed(int index)   {
  if (red_green_flipped) {
    pixels->setPixelColor(index, pixels->Color(0, 250, 0));
  } else {
    pixels->setPixelColor(index, pixels->Color(250, 0, 0));
  }
}
void setGreen(int index) {
  if (red_green_flipped) {
    pixels->setPixelColor(index, pixels->Color(250, 0, 0));
  } else {
    pixels->setPixelColor(index, pixels->Color(0, 250, 0));
  }
}
void setBlue(int index)  { pixels->setPixelColor(index, pixels->Color(0, 0, 250)); }
void setPurple(int index)  {
  if (red_green_flipped) {
    pixels->setPixelColor(index, pixels->Color(0, 250, 250));
  } else {
    pixels->setPixelColor(index, pixels->Color(250, 250, 0));
  }
}
void setOrange(int index)  { pixels->setPixelColor(index, pixels->Color(150, 150, 0)); }
void setError(int index)  { pixels->setPixelColor(index, pixels->Color(55,200,90)); }

void setOff(int index)  { pixels->setPixelColor(index, pixels->Color(0, 0, 0)); }
void setErrorAll() {
  pixels->clear(); 
  for (int i = 0; i < LED_COUNT; ++i) {
    setError(i);
  }
  pixels->show(); 
}
void setOffAll() {
  pixels->clear(); 
  for (int i = 0; i < LED_COUNT; ++i) {
    setOff(i);
  }
  pixels->show(); 
}
void setBlueAll() {
  pixels->clear(); 
  for (int i = 0; i < LED_COUNT; ++i) {
    setBlue(i);
  }
  pixels->show(); 
}
void setRedAll() {
  pixels->clear(); 
  for (int i = 0; i < LED_COUNT; ++i) {
    setRed(i);
  }
  pixels->show(); 
}
void setGreenAll() {
  pixels->clear(); 
  for (int i = 0; i < LED_COUNT; ++i) {
    setGreen(i);
  }
  pixels->show(); 
}

void updateAgentStatusLed(int ledIndex, const String status) {
  if (ledIndex < 0 || ledIndex >= RINGERS) { Serial.println("ledIndex out of bounds abort"); return; }
  ringers[ledIndex].on = false;
  if (status == "inbound" || status == "outbound" || status == "video_member") {
    setRed(ledIndex);
  } else if (status == "wrapup") {
    setPurple(ledIndex);
  } else if (status == "offline" || status == "" || status == "null" || status == "video_member_end") {
    setOff(ledIndex);
  } else if (status == "online") {
    setGreen(ledIndex);
  } else if (status == "ringing") {
    Serial.printf("toggle ringing for agent at %d\n", ledIndex);
    ringers[ledIndex].on = true;
    ringers[ledIndex].lastRing = millis();
  } else {
    Serial.println("configure pixels for custom status");
    for (int i = 0; i < MAX_CUSTOM_STATUS; ++i) {
      if (status == conf.custom_status_index[i]) {
        int g = conf.custom_status_color[i][1], r = conf.custom_status_color[i][0], b = conf.custom_status_color[i][2];
        r = (r * 20) >> 8;
        g = (g * 20) >> 8;
        b = (b * 20) >> 8;
        pixels->setPixelColor(ledIndex, pixels->Color(g, r, b));
        break;
      }
    }

  }
  pixels->show();
}

void locateTick() {
  if (LocateLED > -1) {
    locateCycles++;
    if (locateCycles  < 10) {
      setOrange(LocateLED);
      pixels->show();
      delay(1000);
      Serial.printf("locating %d cycles: %d\n", LocateLED, locateCycles);
    } else {
      locateCycles = 0;
      LocateLED = -1;
      setOffAll();
      refreshAllAgentStatus();
      Serial.println("locate done resume all");
    }
  }
}

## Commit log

2021-10-25 more work on login flow
2021-11-04 test socketio
2021-11-07 finished testing with 4 leds... maybe we can try scaling this up 2 8?
2021-11-07 adding logic to handle socket re-connection (maybe don't need two booleans...)
2021-11-09 fixing reset and fixed a crash caused by a serial printf
    [main.cpp]
2021-11-12 adding design files
    [frame-lock1.stl, frame-lock2.stl, led-frame.stl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]
2021-11-12 updating to print with higher temps
2021-11-13 update designs to optimize for faster print times and less material per case
    [led-frame.stl, led-top.stl, leg1.stl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]
2021-11-13 remove pcb peg's they are too small to print quickly
    [led-frame.stl, led-top.stl]
2021-11-13 slightly more optimized layout with 2 parts per print
2021-11-13 fix for ringers we have LED_COUNT ringers
    [main.cpp]
2021-11-14 sync status using group status call, limited to 10 agents per request but perfect for status station with only 8 led's per node
2021-12-02 add 3mf files
    [led-frame.3mf, led-top.3mf, leg1.3mf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]
2021-12-04 ran into a long running case where the token expired
2021-12-16 usability updates, locate led and possible wifi recovery if lost
    - locate led will change led to yellow/orange for 10 seconds and then refetch status on all leds
    - wifi recovery if the wifi in the office is reset (common as we're getting the new office setup working)
    - we have 8 seats per cube run, this change does reset the device because of eeprom being invalid
    [main.cpp]
2021-12-16 adding some design's for wiring and mounting to exterior cube walls
    [CTM_Status_Station_Design_v24.sch, CTM_Status_Station_Design_v45.brd, Case v19.step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]
2021-12-17 fix issues related to led locate
    [main.cpp]
2022-03-13 monitor videos total to ensure we can track on a video
2022-06-08 add feature to support different lights with rgb flipped
    [main.cpp]
2022-07-02 rework for feather board with display
    [main.cpp]
2022-07-02 use the native esp32 HTTPClient
2022-09-29 gotta remember pin out for lights can be 13 or 25 depending on board configuration
2022-10-20 avoid resetting all settings when we just need to reset the wifi
    [main.cpp]
2022-12-02 adding build support for tinys3, pico w not possible due to lack of eeprom
2023-01-23 ran into issue with board not being init and the length of the ssid being too long should* be a good indicator
    [main.cpp]
2024-02-29 adding debug for insight into the url that fails
    [main.cpp]
2024-02-29 avoid dumping the large request
    [main.cpp]
2024-08-18 Increase custom status break out styles/scripts
    * fix a memory corruption issue if some custom statuses are not used.
    [main.cpp]
2024-08-18 adding button back with a shield need to avoid pulldown
    [main.cpp]
2024-08-18 TODO: make the led count configurable
2025-12-02 fix potential buffer overflows
    [main.cpp]
2025-12-02 more memory safety and avoid unnecessary group request
    [main.cpp]
2025-12-02 fix another memory bug
    [main.cpp]
2025-12-03 use local JsonDocument to avoid multi-threaded writes to shared memory that could* lead to corruption
    [main.cpp]
2025-12-04 Fix early disconnect bug
    [main.cpp]
